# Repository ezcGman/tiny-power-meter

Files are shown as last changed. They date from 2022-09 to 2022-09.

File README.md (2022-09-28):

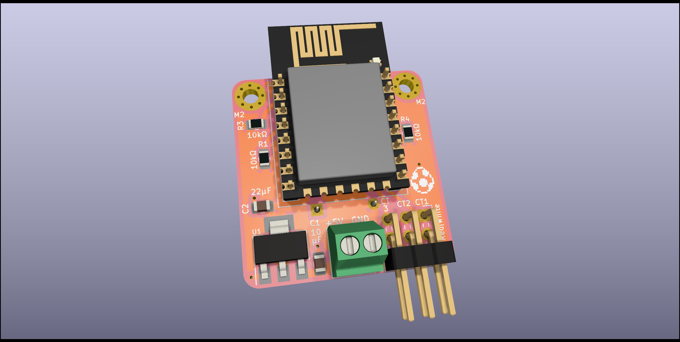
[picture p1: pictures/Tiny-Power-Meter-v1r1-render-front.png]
The PCB


# Tiny 3-phase power meter
A very tiny ESP8266 based PCB to monitor your apartments / homes power consumption using CT clamps and report the reading to Home Assistant using ESPHome!

## Credits
As for all my PCBs: Huge thanks to Quindor from QuinLED.info and also the folks from #pcb-design-talk on his Discord server! Would not have been able to do anything without these people!!

## KiCad dependencies
It might happen that KiCad is missing my custom footprints. You can find and download them here and then add them to KiCad: https://github.com/ezcGman/andys-footprints

## Key features
TBD

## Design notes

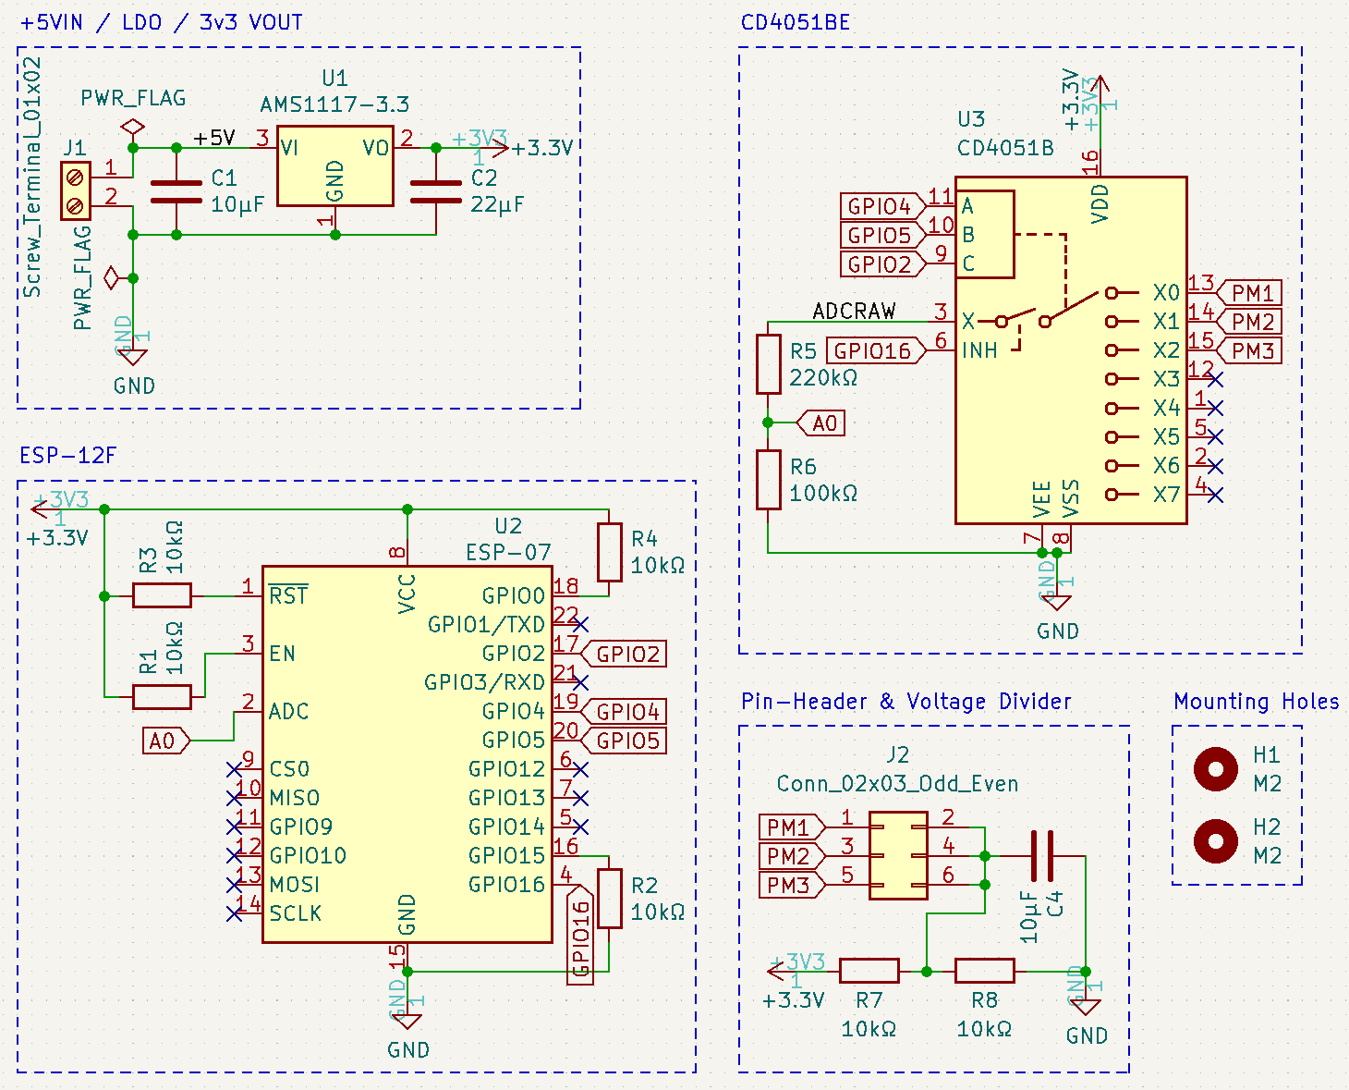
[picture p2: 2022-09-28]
pictures/Tiny-Power-Meter-v1r1-schematic.png

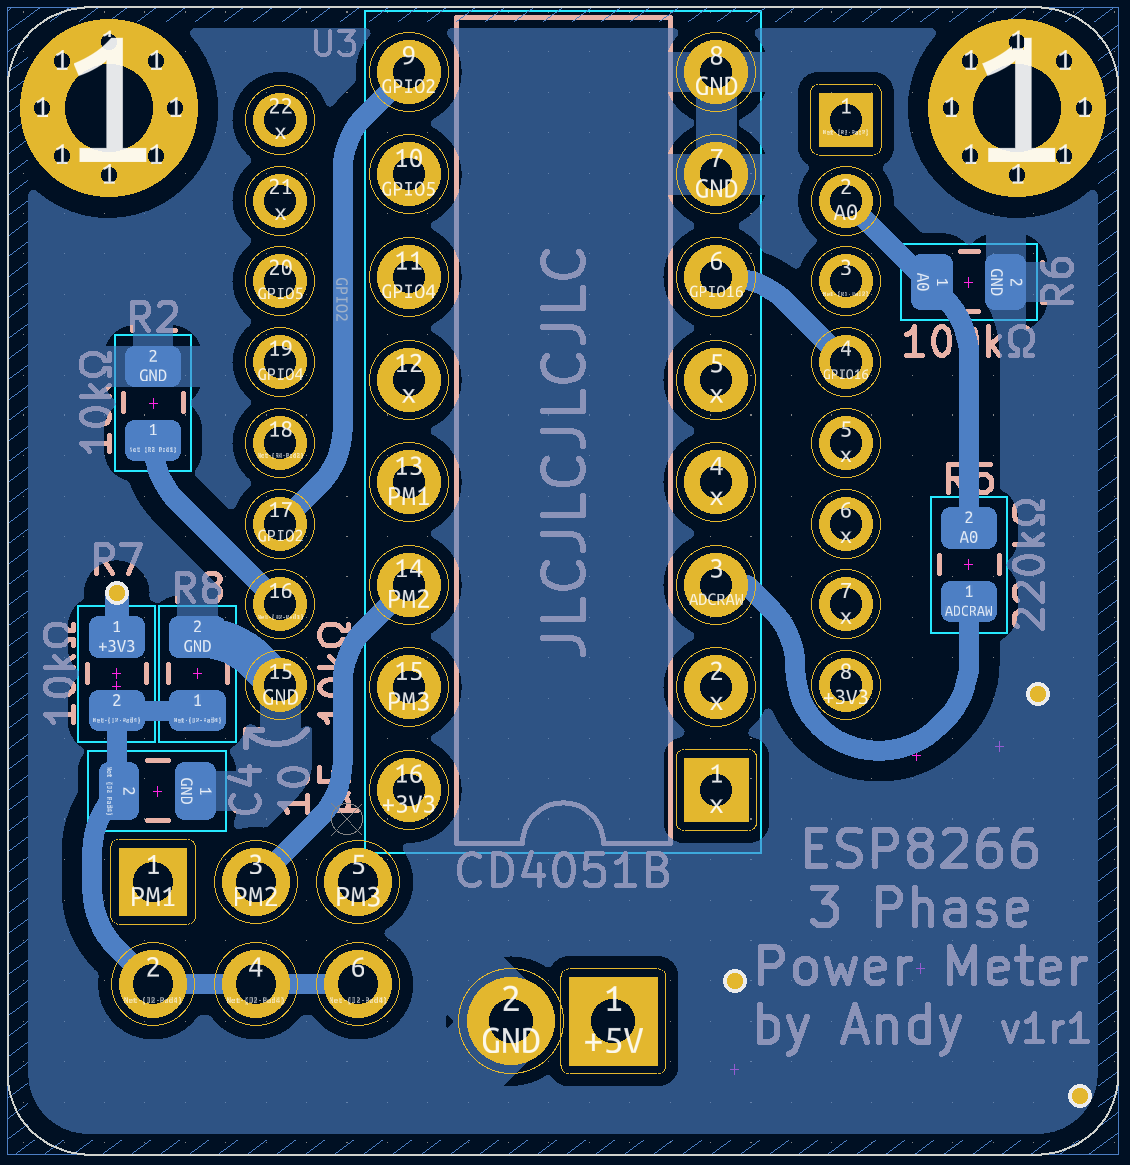
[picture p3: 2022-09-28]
pictures/Tiny-Power-Meter-v1r1-traces-back.png

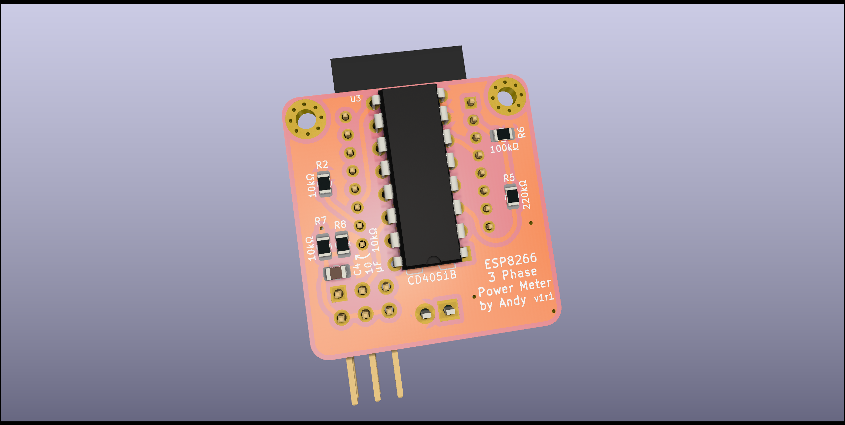
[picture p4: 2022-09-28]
pictures/Tiny-Power-Meter-v1r1-render-back.png

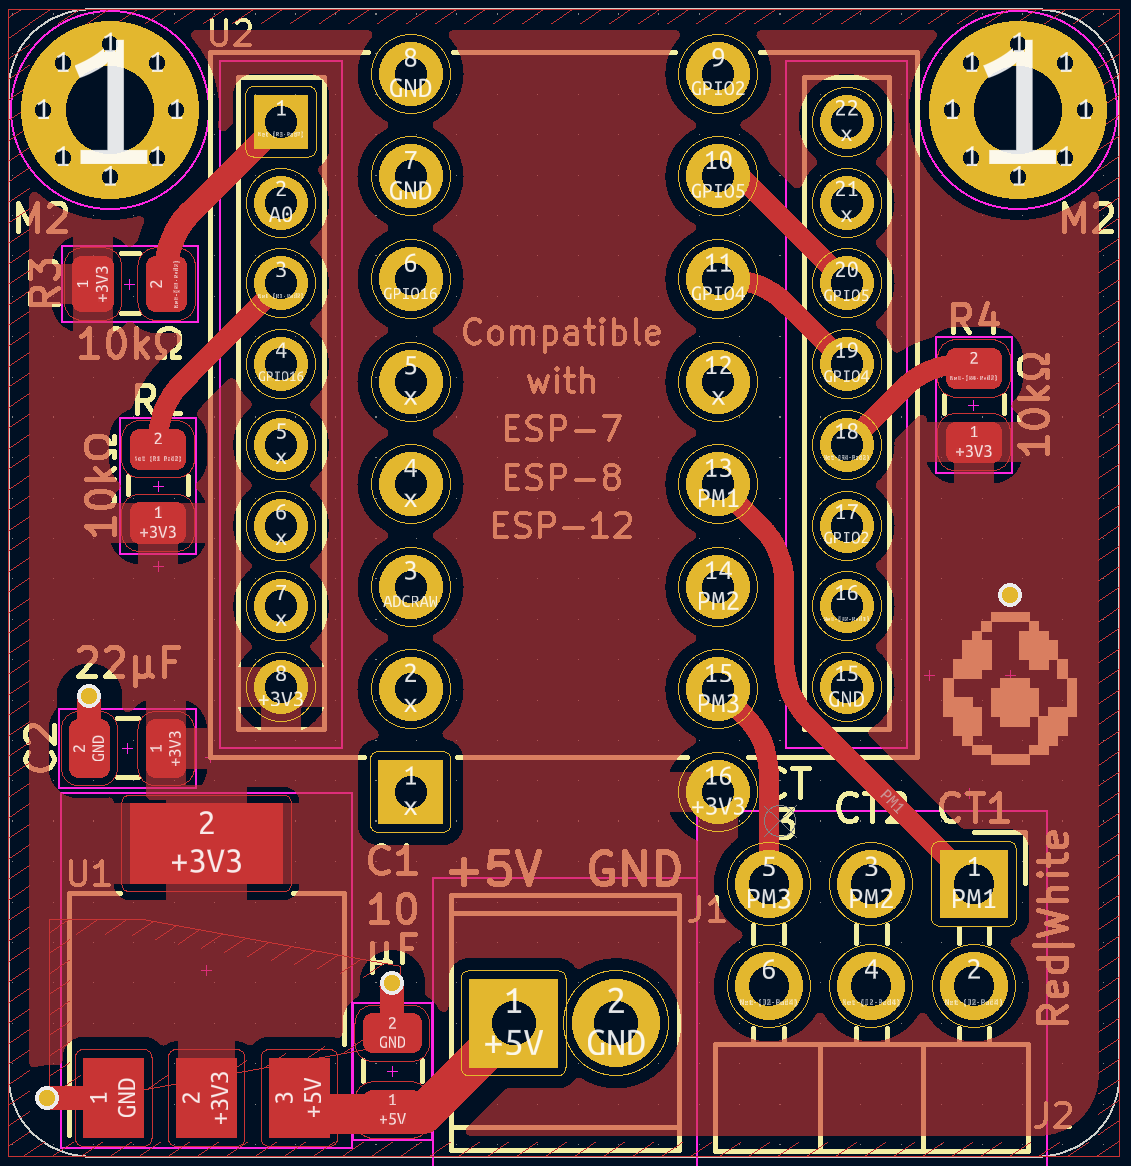
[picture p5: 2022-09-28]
pictures/Tiny-Power-Meter-v1r1-traces-front.png

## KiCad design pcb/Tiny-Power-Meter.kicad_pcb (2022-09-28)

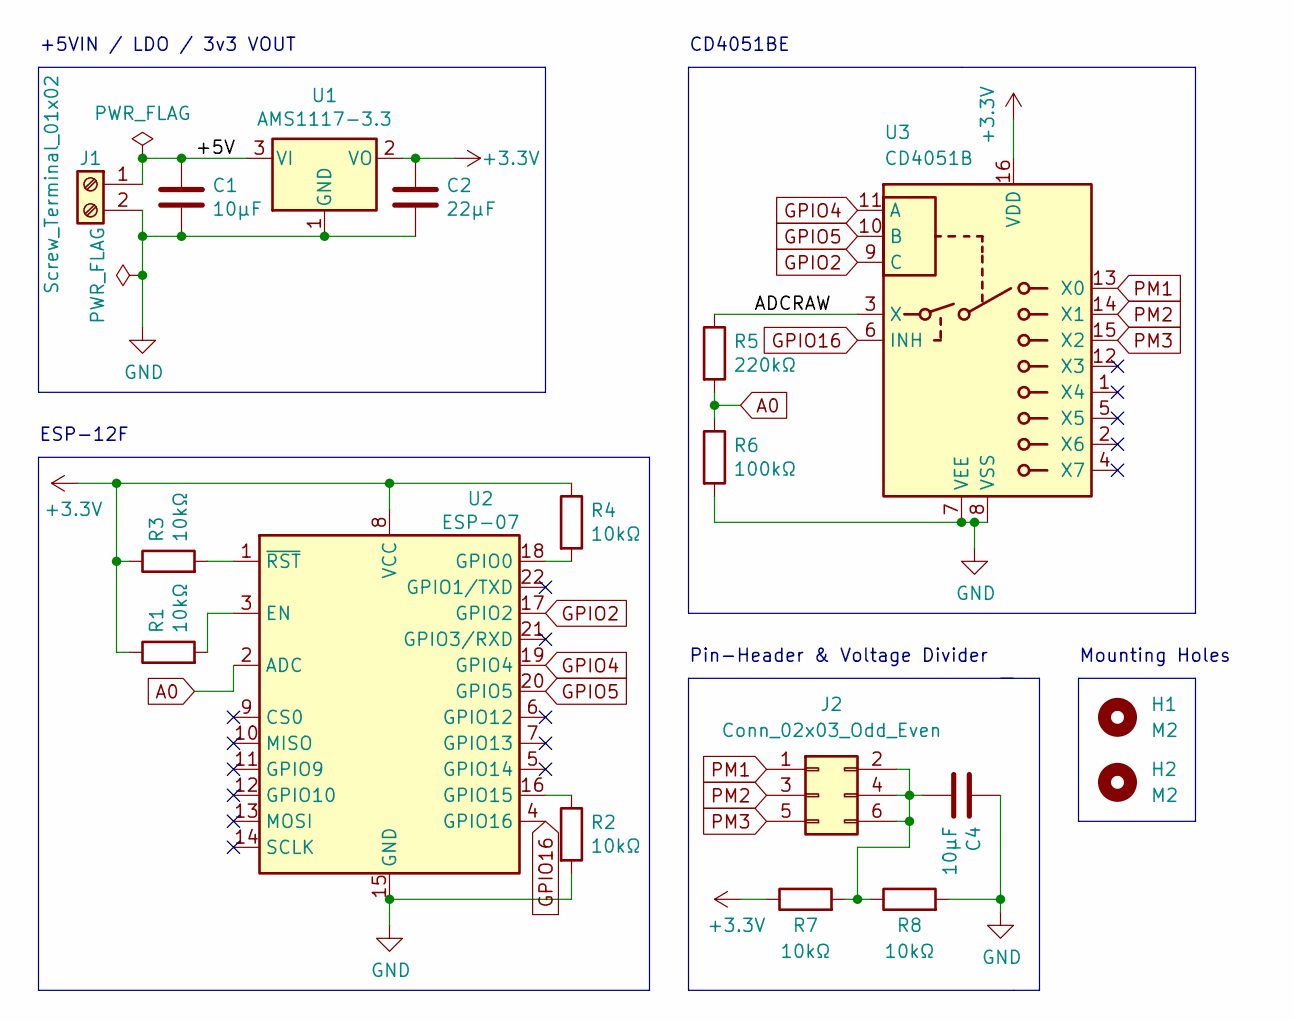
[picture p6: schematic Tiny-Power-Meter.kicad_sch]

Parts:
C1, C4: 10µF; C_0805_2012Metric
C2: 22µF; C_0805_2012Metric
H1, H2: M2; MountingHole_2.2mm_M2_Pad_Via
J1: Screw_Terminal_01x02; TerminalBlock_Phoenix_MPT-0,5-2-2.54_1x02_P2.54mm_Horizonta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
J2: Conn_02x03_Odd_Even; PinHeader_2x03_P2.54mm_Horizontal
R1, R2, R3, R4, R7, R8: 10kΩ; R_0805_2012Metric
R5: 220kΩ; R_0805_2012Metric
R6: 100kΩ; R_0805_2012Metric
U1: AMS1117-3.3; SOT-223-3_TabPin2
U2: ESP-07; ESP-12-Socket-Cutout
U3: CD4051B; DIP-16_W7.62mm

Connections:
+3V3: C2.1, R1.1, R3.1, R4.1, R7.1, U1.2 (VO), U2.8 (VCC), U3.16 (VDD)
/+5V: C1.1, J1.1, U1.3 (VI)
/ADCRAW: R5.1, U3.3 (X)
A0: R5.2, R6.1, U2.2 (ADC)
GND: C1.2, C2.2, C4.1, J1.2, R2.2, R6.2, R8.2, U1.1 (GND), U2.15 (GND), U3.7 (VEE), U3.8 (VSS)
GPIO2: U2.17 (GPIO2), U3.9 (C)
GPIO4: U2.19 (GPIO4), U3.11 (A)
GPIO5: U2.20 (GPIO5), U3.10 (B)
GPIO16: U2.4 (GPIO16), U3.6 (INH)
unnamed: C4.2, J2.2, J2.4, J2.6, R7.2, R8.1
unnamed: R1.2, U2.3 (EN)
unnamed: R2.1, U2.16 (GPIO15)
unnamed: R3.2, U2.1 (~RST)
unnamed: R4.2, U2.18 (GPIO0)
PM1: J2.1, U3.13 (X0)
PM2: J2.3, U3.14 (X1)
PM3: J2.5, U3.15 (X2)

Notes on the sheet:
CD4051BE
Mounting Holes
+5VIN / LDO / 3v3 VOUT
Pin-Header & Voltage Divider
ESP-12F

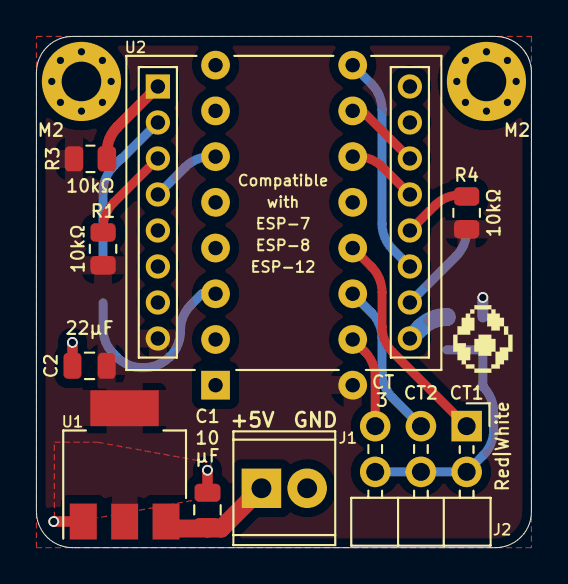
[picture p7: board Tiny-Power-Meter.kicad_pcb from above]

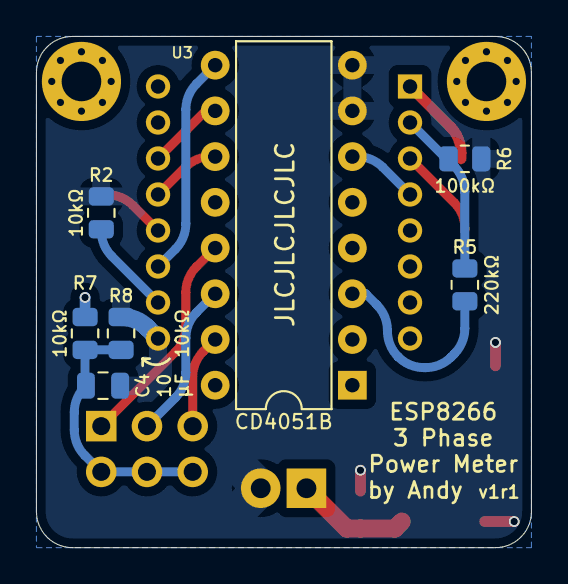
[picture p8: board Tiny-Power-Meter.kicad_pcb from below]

Board: 2 copper layers, 27.5 x 28.4 mm, 18 parts (7 on the bottom side), 17 nets.

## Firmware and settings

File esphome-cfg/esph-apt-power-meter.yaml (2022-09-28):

substitutions:
  update_time: 10s

esphome:
  name: esph-apt-power-meter

esp8266:
  board: esp12e

# Enable logging
logger:

# Enable Home Assistant API
api:
  encryption:
    key: "REPLACE_WITH_SOMETHING"

ota:
  password: "REPLACE_WITH_SOMETHING"

wifi:
  ssid: !secret wifi_ssid
  password: !secret wifi_password

  # Enable fallback hotspot (captive portal) in case wifi connection fails
  ap:
    ssid: "Esph-Apt-Power-Meter"
    password: "REPLACE_WITH_SOMETHING"

mqtt:
  broker: YOUR_MQTT_BROKER_IP
  port: YOUR_MQTT_BROKER_PORT
  username: YOUR_MQTT_BROKER_USER
  password: !secret mqtt_password

captive_portal:

web_server:
  port: 80

# Define s0 to s4 pins. Out multiplexer only has s0 to s2, but this component was made
# for a 16 bit multiplexer, so it has four control pins. So set it to an IO we don't use.    
cd74hc4067:
  - id: cd74hc4067_1
    pin_s0: 4
    pin_s1: 5
    pin_s2: 2
    pin_s3: 12

# Turn the multiplexer on by pulling IO16 LOW 
switch:
  - platform: gpio
    internal: True
    pin: 16
    name: "Enable Multiplexer"
    restore_mode: ALWAYS_OFF


sensor:
  # Read the voltage from the Shelly 1PM in the fuse box
  - platform: mqtt_subscribe
    internal: True
    name: "Apartment Voltage"
    id: apartment_voltage
    topic: home-assistant/shellyplus1pm-a8032abb50dc/voltage
    accuracy_decimals: 1
    device_class: "voltage"
    state_class: "measurement"

  # Our single ADC pin / sensor
  - platform: adc
    id: adc_sensor
    pin: A0

  # Define the multiplexer inputs. Whenever one of these sensors value is requested
  # it will switch to that input and trigger the ADC sensor to read the value
  - platform: cd74hc4067
    id: ct_1_raw
    number: 0
    sensor: adc_sensor
  - platform: cd74hc4067
    id: ct_2_raw
    number: 1
    sensor: adc_sensor
  - platform: cd74hc4067
    id: ct_3_raw
    number: 2
    sensor: adc_sensor

  # Out actual CT clamp sensors that don't have the ADC sensor as input, but one of the
  # multiplexer sensors above. Providing usage in amps.
  - platform: ct_clamp
    id: ct_1_amps
    name: "Apartment Phase 1 Current"
    sensor: ct_1_raw
    update_interval: ${update_time}
    filters:
      - calibrate_linear:
        # Measured value of 0 maps to 0A
        - 0 -> 0
        # Known load: 2.54A
        # Value shown in logs: 0.0154A
        - 0.0154 -> 2.54
  - platform: ct_clamp
    id: ct_2_amps
    name: "Apartment Phase 2 Current"
    sensor: ct_2_raw
    update_interval: ${update_time}
    filters:
      - calibrate_linear:
        # Measured value of 0 maps to 0A
        - 0 -> 0
        # Known load: 2.53A
        # Value shown in logs: 0.0151A
        - 0.0151 -> 2.53
  - platform: ct_clamp
    id: ct_3_amps
    name: "Apartment Phase 3 Current"
    sensor: ct_3_raw
    update_interval: ${update_time}
    filters:
      - calibrate_linear:
        # Measured value of 0 maps to 0A
        - 0 -> 0
        # Known load: 2.53A
        # Value shown in logs: 0.0149A
        - 0.0149 -> 2.53
  # Total apartment usage sensor, providing value in amps
  - platform: template
    name: "Apartment Total Current"
    id: total_amps
    lambda: return id(ct_1_amps).state + id(ct_2_amps).state + id(ct_3_amps).state;
    accuracy_decimals: 2
    unit_of_measurement: A
    device_class: current
    update_interval: ${update_time}

  # Create wattage sensors that we will use to build a kWh sensor HA will find and use in the Energy Dashboard
  - platform: template
    name: "Apartment Phase 1 Watts"
    id: phase_1_watts
    lambda: return id(ct_1_amps).state * id(apartment_voltage).state;
    accuracy_decimals: 2
    unit_of_measurement: W
    device_class: power
    update_interval: ${update_time}
  - platform: template
    name: "Apartment Phase 2 Watts"
    id: phase_2_watts
    lambda: return id(ct_2_amps).state * id(apartment_voltage).state;
    accuracy_decimals: 2
    unit_of_measurement: W
    device_class: power
    update_interval: ${update_time}
  - platform: template
    name: "Apartment Phase 3 Watts"
    id: phase_3_watts
    lambda: return id(ct_3_amps).state * id(apartment_voltage).state;
    accuracy_decimals: 2
    unit_of_measurement: W
    device_class: power
    update_interval: ${update_time}
  # Total apartment usage sensor, providing value in watts
  - platform: template
    name: "Apartment Total Watts"
    id: total_watts
    lambda: return id(total_amps).state * id(apartment_voltage).state;
    accuracy_decimals: 1
    unit_of_measurement: W
    device_class: power
    update_interval: ${update_time}

# kWh sensors that HA will find and use will be created in HA: https://www.home-assistant.io/integrations/integration/#energy
